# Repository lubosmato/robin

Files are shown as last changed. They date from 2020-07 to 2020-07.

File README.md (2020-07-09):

# RoBin
**R**o**B**in project is automatic bin cover opener which uses Arduino Nano board, servo motor and HCSR04 ultrasonic distance measuring sensor. 

RoBin can be put into open state for replacing trash bags by pressing push button.

When an obstacle is too far RoBin will close sooner.

**See it in action:**
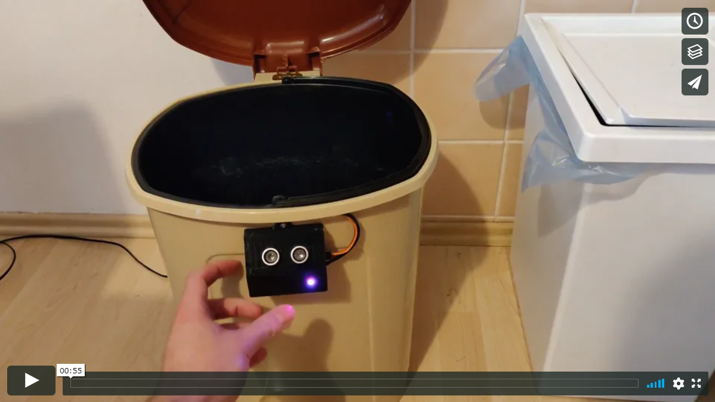
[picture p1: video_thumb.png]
See it in action (https://vimeo.com/436891435)


# Software
PlatformIO project can be build and uploaded to Arduino with PlatformIO extension for VSCode. 

**IMPORTANT** If you want to build your own RoBin, you should tweak parameters first and test whole system without cover attached to prevent any damage to your bin:
```cpp
constexpr int DISTANCE_THRESH = 35; // [cm] obstacle distance threshold
constexpr int SERVO_LIFT_UP = 59; // [deg] lift up (open cover) angle of servo
constexpr int SERVO_NORMAL = 180; // [deg] normal (closed cover) angle of servo
constexpr int SERVO_SPEED_UP = 40; // [%] opening speed of the cover
constexpr int SERVO_SPEED_DOWN = 15; // [%] closing speed of the cover
constexpr int OPEN_TIME = 3000; // [ms] how long should be cover open
constexpr int REACTIVE_TIME = 5000; // [ms] don't lift up for REACTIVE_TIME after closing trash by button
```

# Mechanical
RoBin uses [servo linear rack](https://www.thingiverse.com/thing:2882877) to pull up bin cover. All 3D model `.stl` files are available in `mechanical` folder. 
Linear rack should be printed with stronger materials eg. PETG. For front box (electronic housing) can be used PLA. 
For assembly you will need couple of screws to attach servo to its housing. Servo MG995 is used. 
Linear rack can be attached with screws and nuts to any type of trash bins by making holes into trash bin.
Front box (electronic housing) consists of two parts: base and cover which should be glued together.

**NOTE** Front box needs some sanding with a file tool or sandpaper.

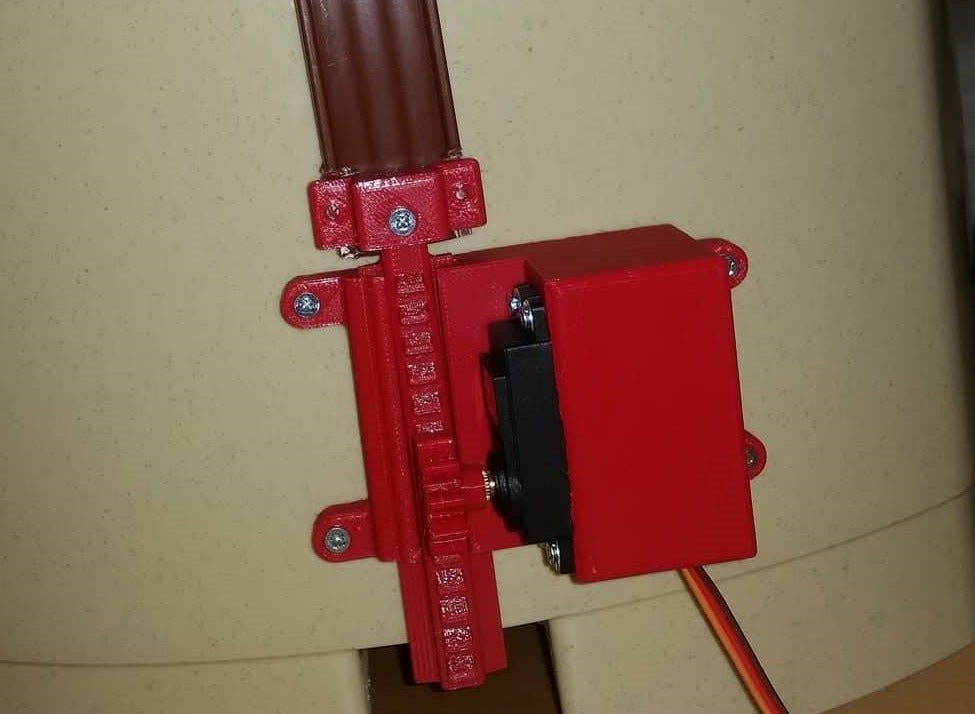
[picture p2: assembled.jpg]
Assembled


# Hardware
- Arduino Nano
- RGB LED
- Push button
- Servo MG995
- HC-SR04 ultrasonic module
- Resistors for RGB LED (eg. 220Ω)

Electronic components can be simply placed on universal PCB.

# Wiring
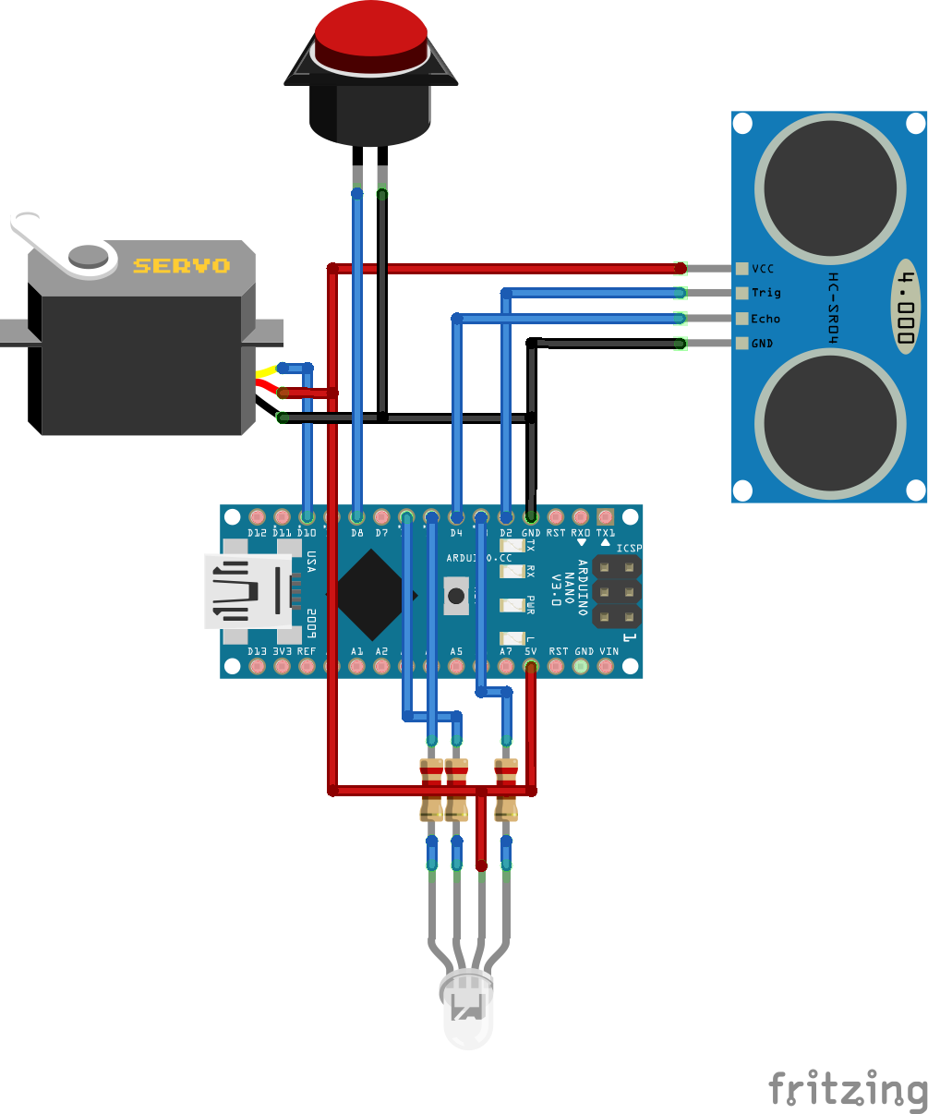
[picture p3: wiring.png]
Wiring


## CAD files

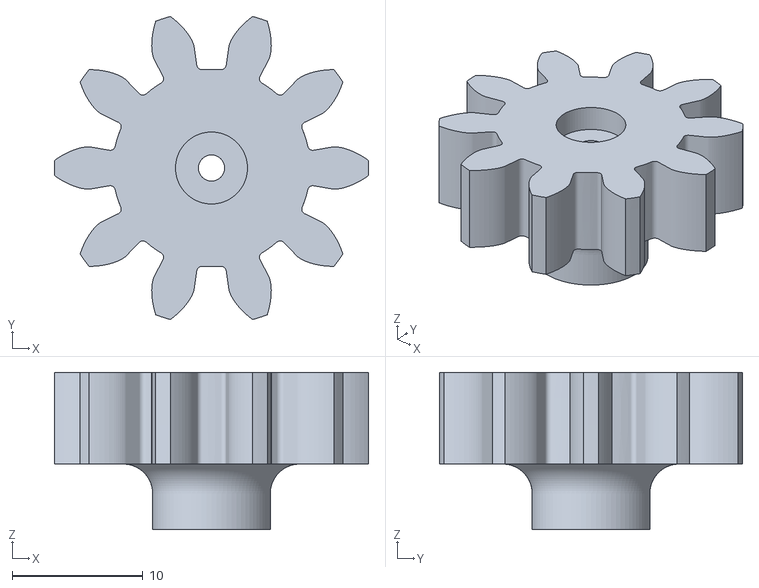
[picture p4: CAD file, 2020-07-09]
mechanical/Spur_Gear_10_teeth.stl
24.0 x 23.2 x 12.0

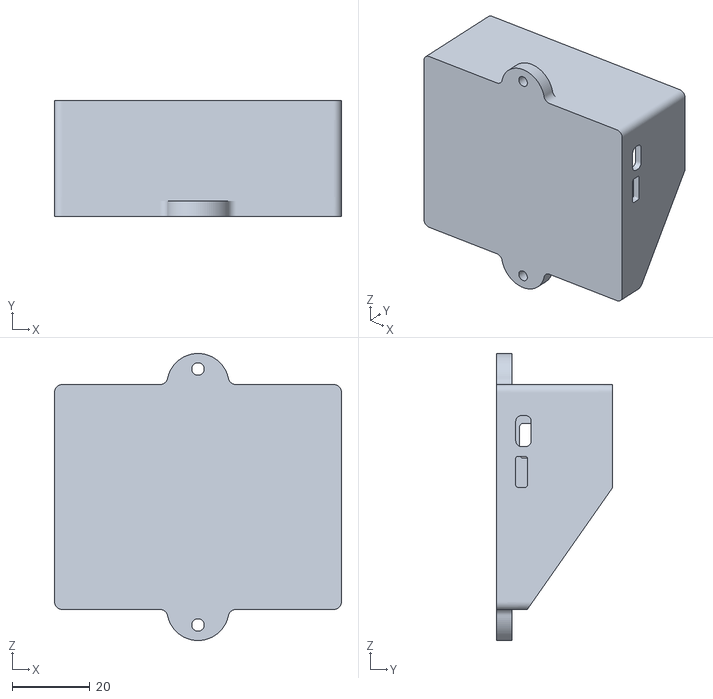
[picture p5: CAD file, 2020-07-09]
mechanical/Electronic_housing_cover.stl
74.0 x 30.0 x 74.0

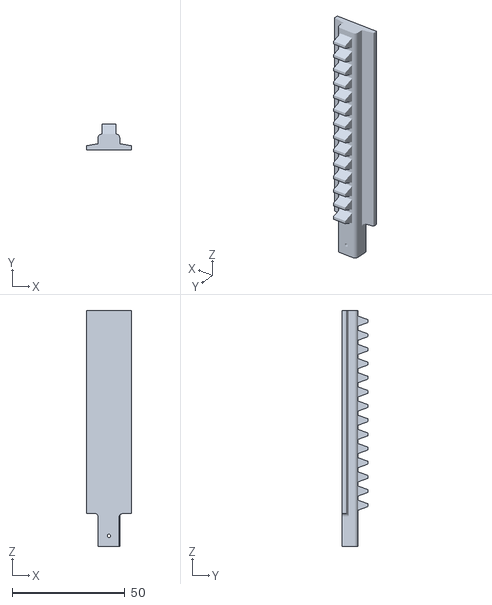
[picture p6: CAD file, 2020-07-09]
mechanical/Rack.stl
20.1 x 11.5 x 104.7

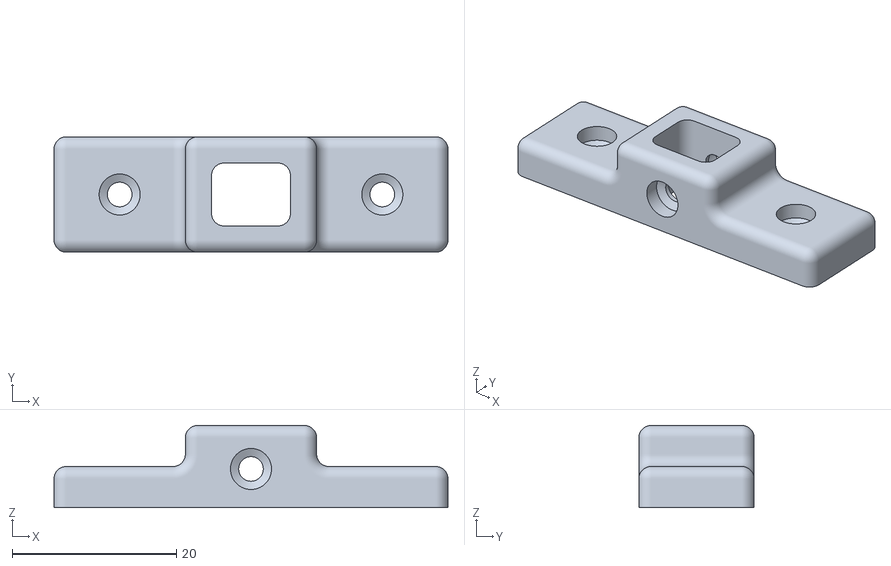
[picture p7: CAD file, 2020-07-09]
mechanical/Slider_holder_2.stl
48.0 x 14.0 x 10.0

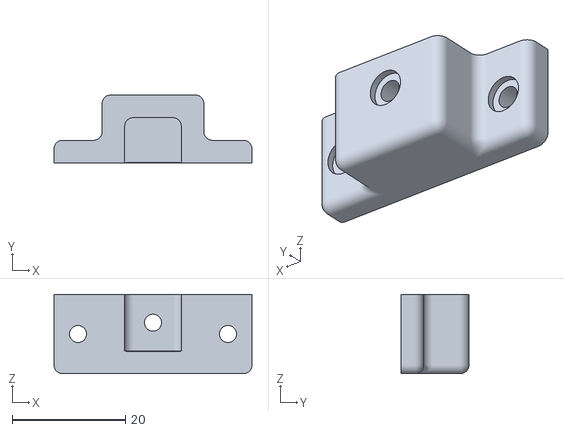
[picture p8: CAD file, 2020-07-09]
mechanical/Slider_holder.stl
35.0 x 12.0 x 14.0

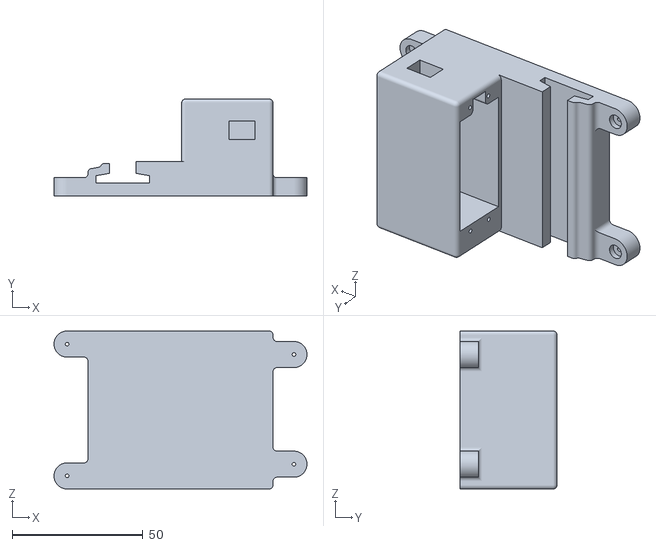
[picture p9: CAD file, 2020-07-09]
mechanical/Base.stl
96.9 x 37.2 x 60.5

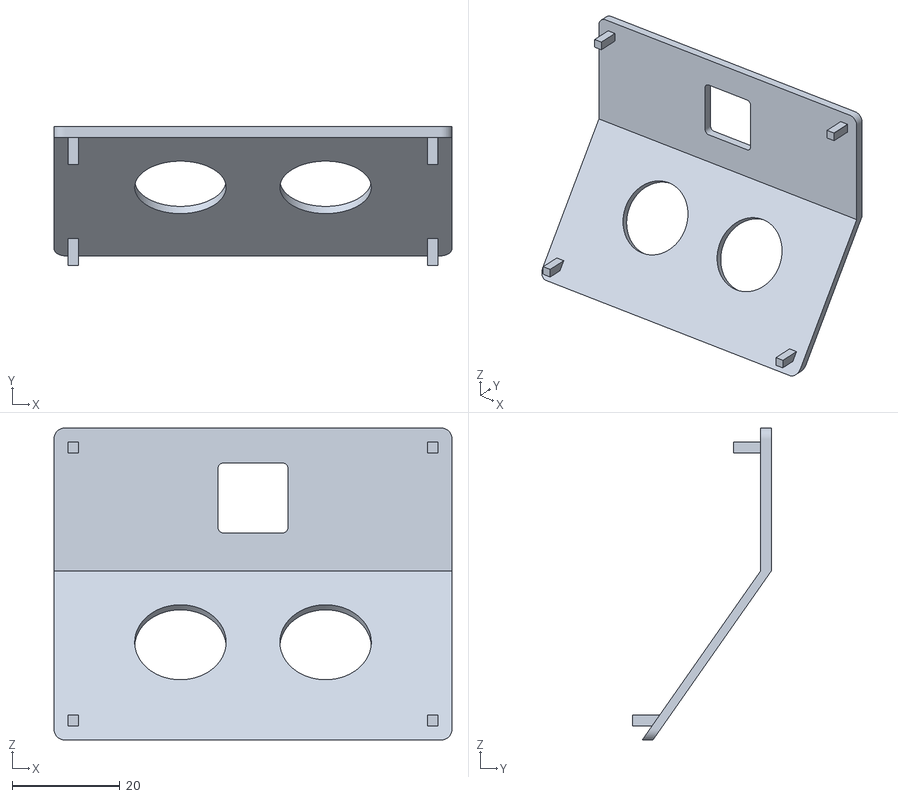
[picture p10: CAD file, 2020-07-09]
mechanical/Electronic_housing_base.stl
74.0 x 25.8 x 58.0

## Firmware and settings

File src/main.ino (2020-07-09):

#include <Arduino.h>
#include <VarSpeedServo.h>
#include <HCSR04.h>

// lights on LOW
constexpr int LED_R_PIN = 3; 
constexpr int LED_G_PIN = 5;
constexpr int LED_B_PIN = 6;
constexpr int SERVO_PIN = 10;
constexpr int ECHO_PIN = 4;
constexpr int TRIG_PIN = 2;
constexpr int BUTTON_PIN = 8;

constexpr int DISTANCE_THRESH = 35; // cm
constexpr int SERVO_LIFT_UP = 59; // deg
constexpr int SERVO_NORMAL = 180; // deg
constexpr int SERVO_SPEED_UP = 40; // %
constexpr int SERVO_SPEED_DOWN = 15; // %
constexpr int OPEN_TIME = 3000; // ms
constexpr int REACTIVE_TIME = 5000; // ms (don't lift up for REACTIVE_TIME after closing trash by button)

//#define DEBUG
#ifdef DEBUG
auto &Debug = Serial;
#else
struct DummySerial {
    template<typename T>
    void print(T &) {}

    template<typename T>
    void println(T &) {}

    void begin(int) {}
} Debug;
#endif

void ledOn(int ledPin);
void ledOff(int ledPin);
void holdUp();
bool isObstacleClose(const double &distance);
void blink(int duration);
void closeBin();
void openBin();
bool isButtonPressed();

VarSpeedServo servo;
UltraSonicDistanceSensor distanceSensor(TRIG_PIN, ECHO_PIN);

void setup()
{
    pinMode(BUTTON_PIN, INPUT_PULLUP);

    pinMode(LED_R_PIN, OUTPUT);
    pinMode(LED_G_PIN, OUTPUT);
    pinMode(LED_B_PIN, OUTPUT);
    
    digitalWrite(LED_R_PIN, HIGH);
    digitalWrite(LED_G_PIN, HIGH);
    digitalWrite(LED_B_PIN, HIGH);
    
    ledOn(LED_R_PIN);

    pinMode(SERVO_PIN, OUTPUT);
    digitalWrite(SERVO_PIN, LOW);

    servo.attach(SERVO_PIN);
    servo.write(SERVO_NORMAL);

    Debug.begin(115200);
}

void loop()
{
    double distance = distanceSensor.measureDistanceCm();
    bool isClose = isObstacleClose(distance);

    if(isButtonPressed()) {
        holdUp();
        return;
    }

    if(isClose) {
        ledOn(LED_G_PIN);
        openBin();

        constexpr int tickInterval = 10;
        constexpr int openTicks = OPEN_TIME / tickInterval;

        for(int i = 0; i < openTicks; i++) {
            if(isButtonPressed()) {
                ledOff(LED_G_PIN);
                holdUp();
                return;
            }
            distance = distanceSensor.measureDistanceCm();
            if(isObstacleClose(distance)) {
                i = 0;
            }
            bool isTooFar = distance == -1.0 || distance >= DISTANCE_THRESH * 3;
            if(isTooFar) {
                i += 100 / tickInterval;
            }
            delay(tickInterval);
        }
        closeBin();
        ledOff(LED_G_PIN);
    }
}

bool isObstacleClose(const double &distance) {
    Debug.print("Distance: ");
    Debug.println(distance);
    return distance >= 4.0 && distance <= DISTANCE_THRESH;;
}

bool isButtonPressed() {
    return digitalRead(BUTTON_PIN) == LOW;
}

void holdUp() {
    ledOn(LED_B_PIN);
    openBin();
    delay(3000);
    while(!isButtonPressed()) {
        delay(1);
    }
    closeBin();
    ledOff(LED_B_PIN);
    blink(REACTIVE_TIME);
}

void ledOn(int ledPin) {
    analogWrite(ledPin, 1022);
}

void openBin() {
    servo.write(SERVO_LIFT_UP, SERVO_SPEED_UP, false);
}

void closeBin() {
    servo.write(SERVO_NORMAL, SERVO_SPEED_DOWN, false);
}

void ledOff(int ledPin) {
    digitalWrite(ledPin, HIGH);
}

void blink(int duration) {
    int ticks = duration / 1000;
    while(ticks > 0) {
        ledOff(LED_R_PIN);
        delay(500);
        ledOn(LED_R_PIN);
        delay(500);
        ticks--;
    }
}

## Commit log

2020-07-09 Add wiring schematic
2020-07-09 Add 3D models
    [Base.stl, Electronic_housing_base.stl, Electronic_housing_cover.stl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]
